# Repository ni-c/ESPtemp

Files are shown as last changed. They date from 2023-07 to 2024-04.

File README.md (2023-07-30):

# ESPtemp

Battery powered ESP8266 controlled temperature and humidity sensor communicating via MQTT protocol (with Home Assistant).

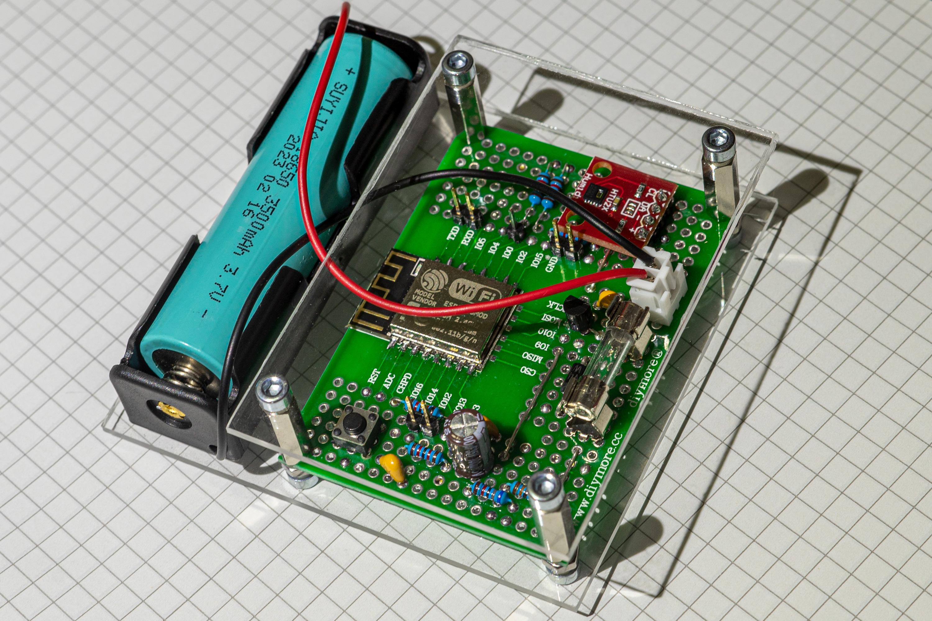
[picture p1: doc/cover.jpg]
ESPTemp v1.0 with case


ESPtemp is a battery-powered device that detects temperature and humidity and transmits them to a server (like [Home Assistant](https://www.home-assistant.io/)) via WiFi using [MQTT](https://mqtt.org/). It measures the current temperature, humidity and battery voltage, transmits them and then goes into deep sleep for 5 minutes to save energy. After that, the process is repeated. To make the connection to the WiFi as fast as possible, the WiFi channel and the MAC address of the router are stored in the RTC memory of the microcotroller and used to speed up the next connection attempt.

The device uses an ESP-12F microcontroller to process and transmit the data. Temperature and humidity are measured by a HTU21D sensor. The required operating voltage of 3.3V for the MCU and the sensor is provided by a MCP1700-3302E low dropout voltage regulator. The power supply is a lithium-ion battery type 18650 with 3.7V and 3500mAh. The protection of the circuit and the lithium-ion battery is ensured by a 200mA fine-wire fuse. The circuit is built on a double-sided prototype PCB board for ESP8266 and ESP32.

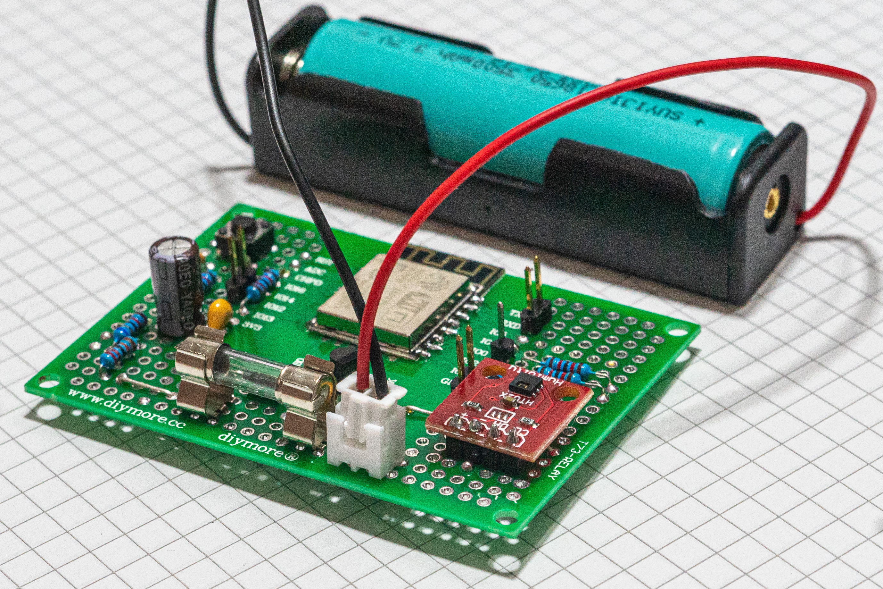
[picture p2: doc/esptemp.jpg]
ESPTemp v1.0 without case


### Part list

- [Prototype PCB board for ESP8266](https://aliexpress.com/item/32841008259.html)
- [ESP-12F](https://aliexpress.com/item/1005003766943788.html)
- [HTU21D](https://aliexpress.com/item/1005003761577887.html)
- [MCP1700](https://aliexpress.com/item/1005001608339185.html)
- [18650 lithium-ion battery](https://aliexpress.com/item/1005005313027198.html)
- [Battery Holder](https://aliexpress.com/item/1005005254487864.html)
- 1N4007 Diode
- 12 kΩ Resistor *(5 pieces)*
- 68 kΩ Resistor
- 220 kΩ Resistor
- 1000 µF Electrolyte capacitor
- 100 nF Ceramic capacitor *(2 pieces)*
- 1 nF Ceramic capacitor
- Micro push button switch (4 pin)
- Jumper connectors
- 200 mA Fuse
- Fuse holder
- Wire

## Schematics

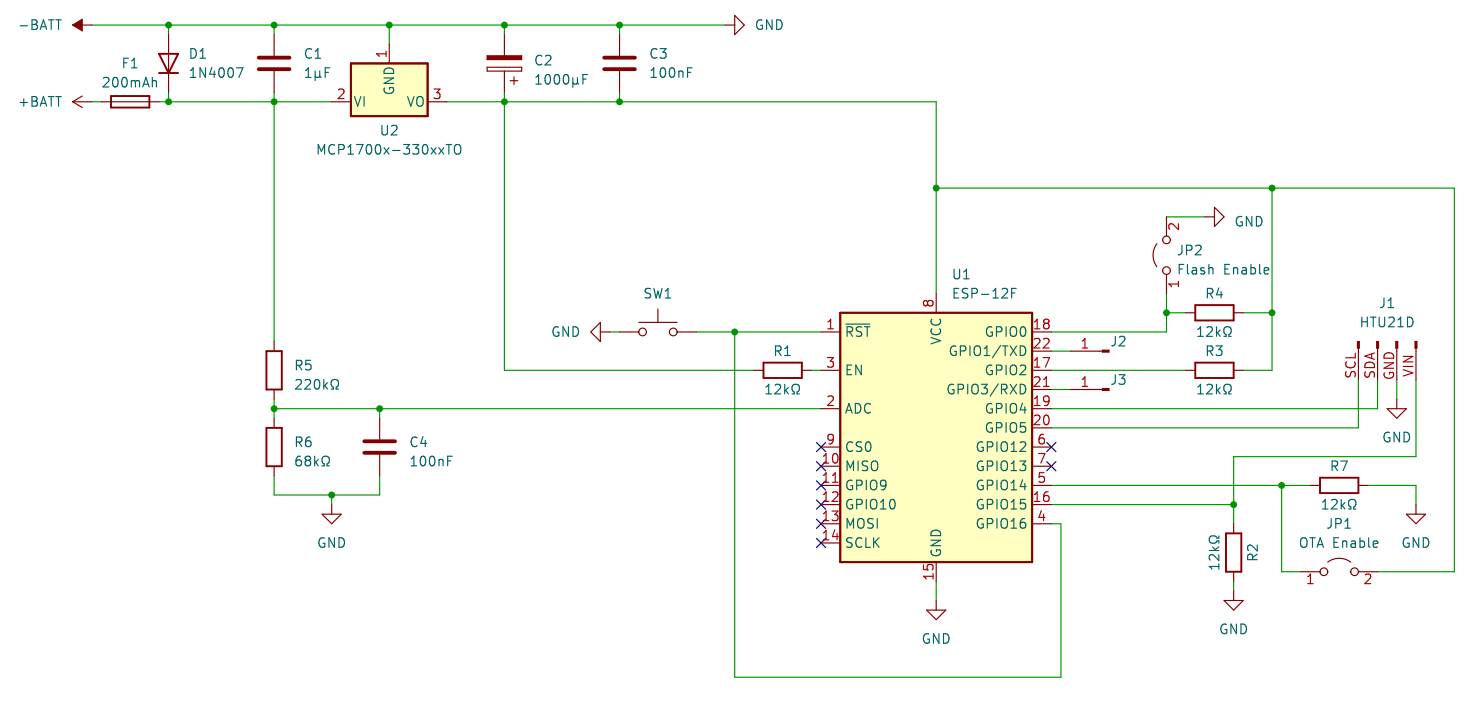
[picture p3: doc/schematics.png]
Schematics


## Perfboard layout

### Front

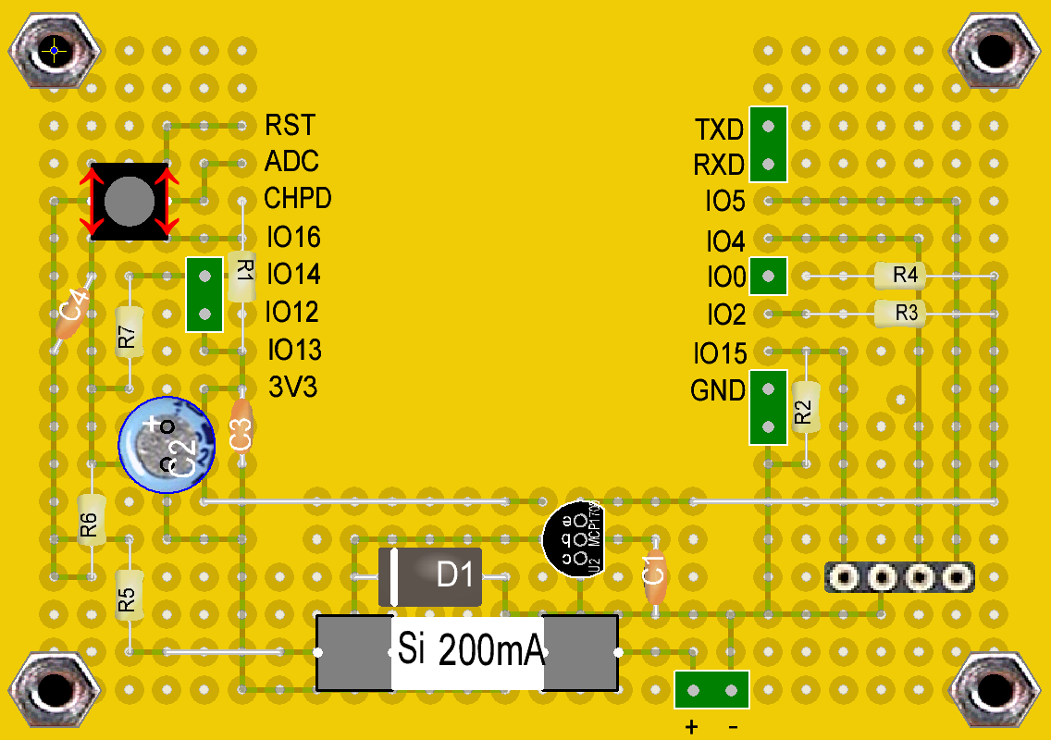
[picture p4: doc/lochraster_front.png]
Perfboard front


### Back

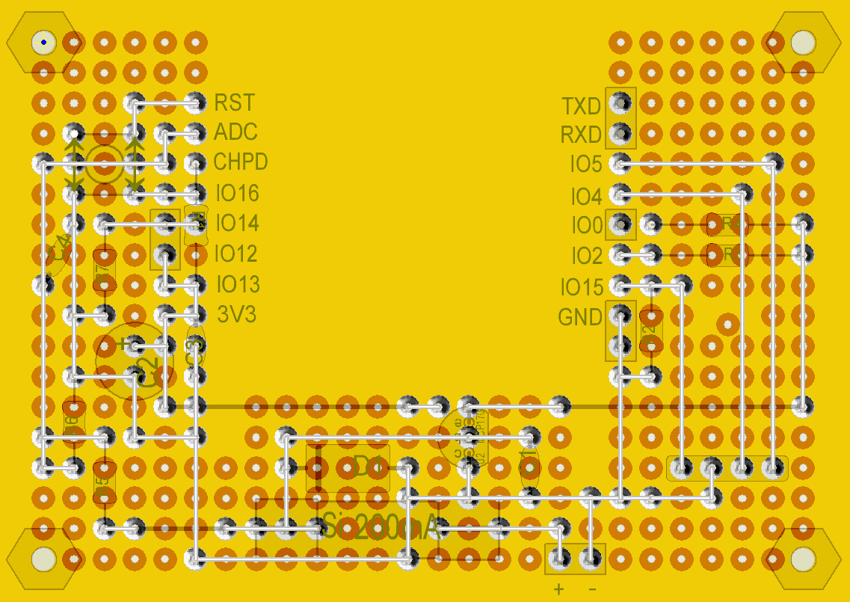
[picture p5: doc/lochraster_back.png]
Perfboard back


## Assembled

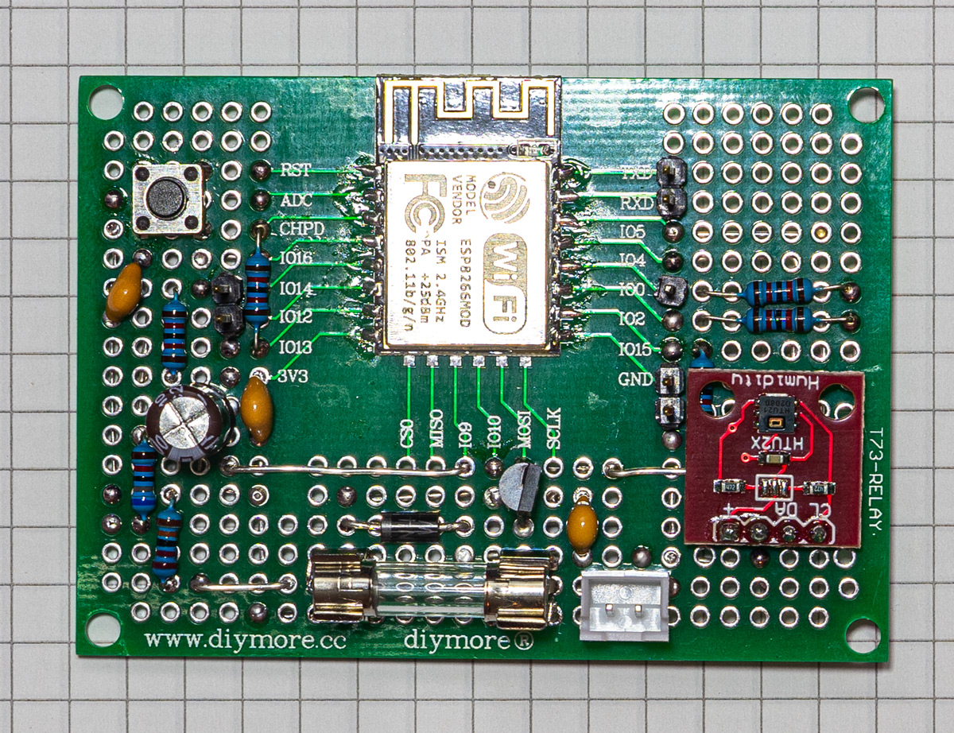
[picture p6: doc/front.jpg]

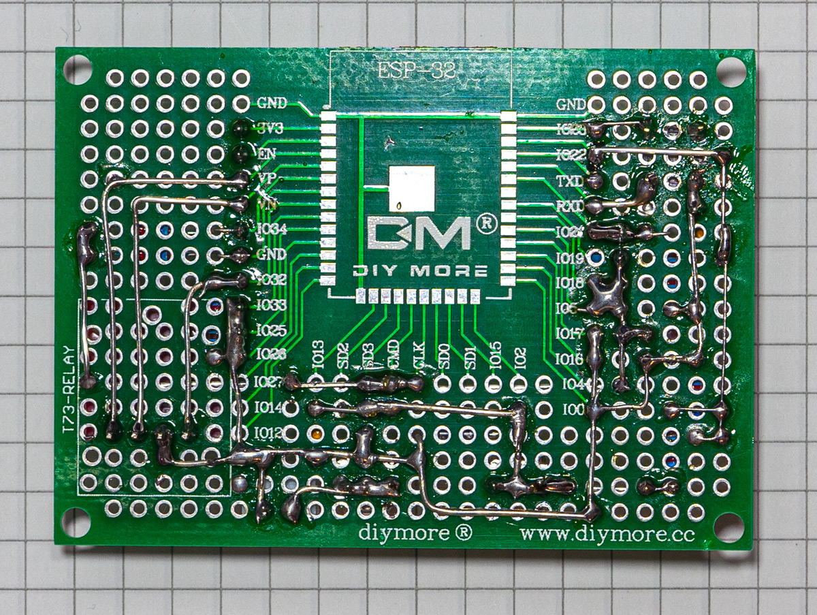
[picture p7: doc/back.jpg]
Perfboard back


## Firmware

The firmware is written in C++ using [Visual Studio Code](https://code.visualstudio.com/) with the [PlatformIO](https://platformio.org/) extension.

> ⚠️ Before building the firmware be sure to copy the file `include\config.h.example` to `include/config.h` and change the WiFi and MQTT credentials as well as the other settings in the new file.

### Flash via serial connection

Connect RX, TX and GND to your serial interface or [USB-to-TTL converter](https://aliexpress.com/item/32531899568.html). To [enter flash mode on the ESP-12F](https://lukelogbook.tech/2018/02/08/flash-code-to-esp8266-esp-12-module-step-by-step-guide/) you must connect **GPIO0** to **GND** and reset the MCU.

### Flash via OTA

To flash the ESP8266 Over-The-Air, connect **GPIO 14** to **VCC** and reset the ESP8266. After reboot it will enter the *"OTA wait loop"*. The flashing blue LED indicates that the MCU is waiting for the OTA firmware update.

## TODOs

- Create an [ESPHome](https://esphome.io/) configuration to use the hardware without the firmware provided here

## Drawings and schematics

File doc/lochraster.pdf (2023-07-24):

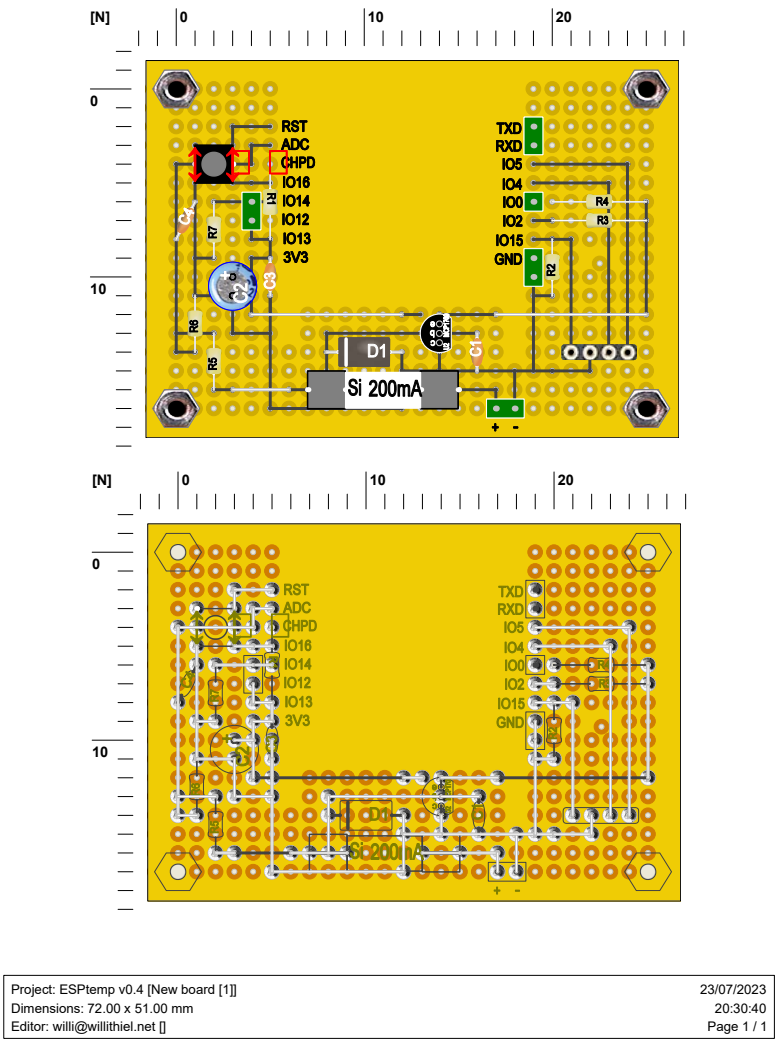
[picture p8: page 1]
23/07/2023 20:30:40 Page 1 / 1

Project: ESPtemp v0.4 [New board [1]]
Dimensions: 72.00 x 51.00 mm
Editor: willi@willithiel.net []

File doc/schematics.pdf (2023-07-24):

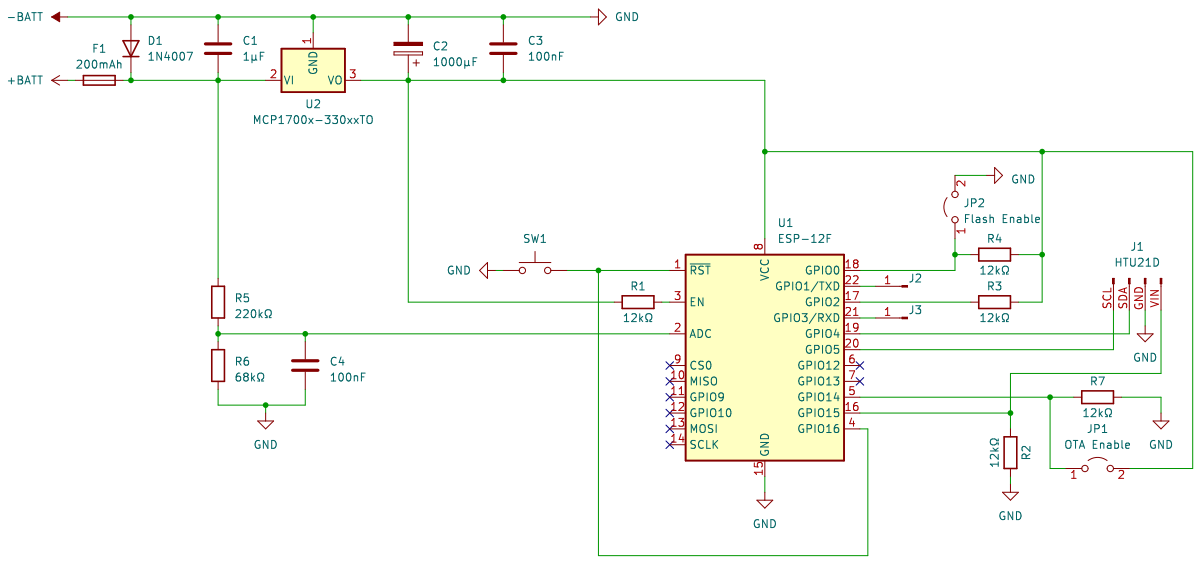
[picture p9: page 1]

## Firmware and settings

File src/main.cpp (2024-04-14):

#include <Arduino.h>
#include <Adafruit_HTU21DF.h>
#include <ESP8266WiFi.h>
#include <ArduinoOTA.h>
#include <PubSubClient.h>
#include <ArduinoJson.h>

#include "config.h"

#ifndef ESPTEMP_VERSION
#define ESPTEMP_VERSION "v1.1" /**< The current version of the ESPtemp firmware*/
#endif

#ifndef OTA_ENABLE_GPIO
#define OTA_ENABLE_GPIO 14 /**< Connect this GPIO Pin to VCC to enter OTA wait loop after reset */
#endif

#ifndef HTU21DF_VCC_GPIO
#define HTU21DF_VCC_GPIO 15 /**< VCC for HTU21DF sensor */
#endif

#ifndef SLEEPTIME
#define SLEEPTIME 300e6 /**< Time in deepsleep */
#endif

#ifndef SLEEPTIME_EXTENDED
#define SLEEPTIME_EXTENDED 21600e6 /**< Time in deepsleep if an error occured while trying to connect to wifi (to avoid battery drainage) */
#endif

#ifndef DEBUG
#define DEBUG 0 /**< Set to 1 to debug over serial */
#endif

#ifndef OTA
#define OTA 1 /**< Set to 1 to enable OTA waiting loop */
#endif

#if DEBUG
#define D_SerialBegin(...) Serial.begin(__VA_ARGS__)
#define D_print(...) Serial.print(__VA_ARGS__)
#define D_write(...) Serial.write(__VA_ARGS__)
#define D_println(...) Serial.println(__VA_ARGS__)
#define D_printf(...) Serial.printf(__VA_ARGS__)
#define D_timestamp() Serial.printf("[%lu] ", millis())
#else
#define D_SerialBegin(bauds)
#define D_print(...)
#define D_write(...)
#define D_println(...)
#define D_printf(...)
#define D_timestamp()
#endif

unsigned long startMillis;

float humidity;
float temperature;
float batteryVoltage;
int8_t batteryPercentage;
uint_fast16_t adcValue;
char error[15];

uint8_t wifiRetries = 0;
uint_fast16_t i = 0;

bool isHTU21DFready = false;
bool isBatteryVoltageReady = false;
bool isWifiStarted = false;
bool isWifiReady = false;
bool isRegularWifi = false;
bool isMQTTStarted = false;
bool isMQTTReady = false;
bool isRtcValid = false;
bool isOTAEnabled = false;

uint8_t ledState = HIGH;

Adafruit_HTU21DF htu = Adafruit_HTU21DF();

WiFiClient wifiClient;
PubSubClient pubSubclient(wifiClient);

struct
{
    uint32_t crc32;    // 4 bytes
    uint8_t channel;   // 1 byte,   5 in total
    uint8_t ap_mac[6]; // 6 bytes, 11 in total
} rtcData;

// the CRC routine
uint32_t calculateCRC32(const uint8_t *data, size_t length)
{
    uint32_t crc = 0xffffffff;
    while (length--)
    {
        uint8_t c = *data++;
        for (uint32_t i = 0x80; i > 0; i >>= 1)
        {
            bool bit = crc & 0x80000000;
            if (c & i)
            {
                bit = !bit;
            }

            crc <<= 1;
            if (bit)
            {
                crc ^= 0x04c11db7;
            }
        }
    }

    return crc;
}

// Read the battery voltage from the ADC
float readBatteryVoltage(void)
{
    adcValue = analogRead(A0);
    batteryVoltage = adcValue * 0.004;
    batteryPercentage = (int8_t)((adcValue - 863) / 1.6);

    if (batteryVoltage <= 3.3)
    {
        D_timestamp();
        D_println("Battery low. Going to long deep sleep. Good night.");
        ESP.deepSleep(0);
    }

    D_timestamp();
    D_println("ADC Reading ready");
    D_timestamp();
    D_printf("Battery voltage: %.1f V, Battery Percentage: %i", batteryVoltage, batteryPercentage);
    D_println();
    return batteryVoltage;
}

void setup()
{
    D_SerialBegin(115200);

    // internal LED off
    pinMode(LED_BUILTIN, OUTPUT);
    digitalWrite(LED_BUILTIN, HIGH);

    // we disable WiFi, coming from DeepSleep, as we do not need it right away
    WiFi.mode(WIFI_OFF);
    WiFi.forceSleepBegin();

    D_println();
    D_timestamp();
    D_printf("CpuFreqMHz: %u MHz\n", ESP.getCpuFreqMHz());
    D_timestamp();
    D_print("MAC Address: ");
    D_println(WiFi.macAddress());

    // enable HTU21DF_VCC
    pinMode(HTU21DF_VCC_GPIO, OUTPUT);
    digitalWrite(HTU21DF_VCC_GPIO, HIGH);
    htu.begin();

    // Wait minimum sampling period
    startMillis = millis();

    if (ESP.rtcUserMemoryRead(0, (uint32_t *)&rtcData, sizeof(rtcData)))
    {
        // Calculate the CRC of what we just read from RTC memory, but skip the first 4 bytes as that's the checksum itself.
        uint32_t crc = calculateCRC32(((uint8_t *)&rtcData) + 4, sizeof(rtcData) - 4);
        if (crc == rtcData.crc32)
        {
            isRtcValid = true;
        }
    }

#if OTA
#if DEBUG
    ArduinoOTA.onStart([]()
                       {
        String __type;
        if (ArduinoOTA.getCommand() == U_FLASH)
            __type = "sketch";
        else // U_SPIFFS
            __type = "filesystem";
        D_timestamp();
        D_println("(OTA) Update starting: " + __type); });

    ArduinoOTA.onEnd([]()
                     {
        D_timestamp();
        D_println("(OTA) Update finished "); });

    ArduinoOTA.onError([](ota_error_t error)
                       {
        D_print("(OTA) Error[");
        D_print(error);
        D_print("]: ");
        if (error == OTA_AUTH_ERROR)
            D_println("Auth Failed");
        else if (error == OTA_BEGIN_ERROR)
            D_println("Begin Failed");
        else if (error == OTA_CONNECT_ERROR)
            D_println("Connect Failed");
        else if (error == OTA_RECEIVE_ERROR)
            D_println("Receive Failed");
        else if (error == OTA_END_ERROR)
            D_println("End Failed"); });
#endif
    pinMode(OTA_ENABLE_GPIO, INPUT);
    isOTAEnabled = (digitalRead(OTA_ENABLE_GPIO) == HIGH);
    if (isOTAEnabled)
    {
        D_timestamp();
        D_println("GPIO 14 is high, OTA enabled");
    }
    else
    {
        D_timestamp();
        D_println("GPIO 14 is low, OTA not enabled");
    }
#endif
    D_timestamp();
    D_println("Setup finished");
}

void loop()
{

    /*
     * Step 1:
     * Read temperature and humidity from HTU21DF
     */
    if (!isHTU21DFready)
    {
        // Read sensors
        humidity = htu.readHumidity();
        temperature = htu.readTemperature();

        D_timestamp();
        D_println("HTU21DF Reading ready");
        D_timestamp();
        D_printf("Temperature: %.1f, Humidity: %.1f", temperature, humidity);
        D_println();

        isHTU21DFready = true;
        digitalWrite(HTU21DF_VCC_GPIO, LOW);
    }

    /*
     * Step 2:
     * Start WiFi connection
     */
    if (!isWifiStarted)
    {
        D_timestamp();
        D_println("Starting WiFi");

        WiFi.forceSleepBegin();
        delay(1);
        WiFi.forceSleepWake();
        delay(1);

        // Disable the WiFi persistence.  The ESP8266 will not load and save WiFi settings unnecessarily in the flash memory.
        WiFi.persistent(false);

        // Bring up the WiFi connection
        WiFi.mode(WIFI_STA);
        WiFi.config(ip, dns, gateway, subnet);
        WiFi.hostname(MQTT_CLIENT);

        if (isRtcValid)
        {
            // The RTC data was good, make a quick connection
            D_timestamp();
            D_println("RTC OK, initiate quick connection");
            WiFi.begin(WLAN_SSID, WLAN_PASSWD, rtcData.channel, rtcData.ap_mac, true);
            isRegularWifi = false;
        }
        else
        {
            // The RTC data was not valid, so make a regular connection
            D_timestamp();
            D_println("RTC BAD, initiate regular connection");
            WiFi.begin(WLAN_SSID, WLAN_PASSWD);
            isRegularWifi = true;
        }

        isWifiStarted = true;
    }

    /*
     * Step 3:
     * Read battery voltage from ADC
     */
    if (!isBatteryVoltageReady)
    {
        isBatteryVoltageReady = true;
        readBatteryVoltage();
    }

    /*
     * Step 4:
     * If WiFi is ready: Initialize MQTT client
     * OR
     * Start OTA waiting loop if OTA_ENABLE_GPIO is pulled HIGH
     */
    if (!isWifiReady)
    {
        if (WiFi.status() == WL_CONNECTED)
        {
            D_timestamp();
            D_print("WiFi connected (");
            D_print(WiFi.localIP());
            D_println(")");
            pubSubclient.setServer(MQTT_BROKER, MQTT_PORT);
            isWifiReady = true;

            if (isOTAEnabled)
            {
                D_timestamp();
                D_println("Starting OTA");
                ArduinoOTA.setHostname(MQTT_CLIENT);
                ArduinoOTA.begin();
            }
        }
        else if (((millis() - startMillis) > 5000) && (!isRegularWifi))
        {
            // Try regular connection
            D_timestamp();
            D_println("WiFi timeout, retrying regular connection");
            WiFi.disconnect();
            delay(5);
            WiFi.forceSleepBegin();
            delay(1);
            WiFi.forceSleepWake();
            delay(1);
            WiFi.begin(WLAN_SSID, WLAN_PASSWD);
            isRtcValid = false;
            isRegularWifi = true;
        }
        else if ((millis() - startMillis) > 20000)
        {
            // Wifi connection failed, go to extended sleep
            WiFi.disconnect(true);
            D_timestamp();
            D_println("Connection to WiFi failed, going to extended sleep");
            ESP.deepSleep(SLEEPTIME_EXTENDED, WAKE_RF_DISABLED);
        }
    }
    /*
     * Step 5:
     * Connect to MQTT broker
     */
    else if (!isMQTTStarted)
    {
        if (!pubSubclient.connected())
        {
            D_timestamp();
            D_println("Connecting to MQTT broker");
            pubSubclient.connect(MQTT_CLIENT, MQTT_USER, MQTT_PASSWORD);
            delay(10);
        }
        else
        {
            D_timestamp();
            D_println("MQTT connected");
            isMQTTStarted = true;
        }
    }

    /*
     * Step 5:
     * If all readings are made and WiFi is ready, transmit MQTT data
     */
    if (isMQTTStarted && isWifiReady && isHTU21DFready && !isMQTTReady)
    {
        DynamicJsonDocument doc(1024);
        doc["temperature"] = (int)roundf(10 * temperature) / 10.0;
        doc["humidity"] = (int)roundf(10 * humidity) / 10.0;
        doc["batteryVoltage"] = (int)roundf(100 * batteryVoltage) / 100.0;
        doc["batteryPercentage"] = batteryPercentage;
        doc["firmwareVersion"] = ESPTEMP_VERSION;

        char json[128];
        serializeJson(doc, json);

        D_timestamp();
        D_print("MQTT Publish: ");
        D_print(MQTT_TOPIC);
        D_print(" ");
        D_println(json);

        pubSubclient.loop();
        pubSubclient.publish(MQTT_TOPIC, json);
        delay(10);

        isMQTTReady = true;
    }

    if (!isOTAEnabled)
    {
        /*
         * Step 6:
         * Save WiFi data to RTC and go to deep sleep again
         */
        if (isMQTTReady)
        {
            // Write current connection info to RTC
            if (!isRtcValid)
            {
                rtcData.channel = WiFi.channel();
                memcpy(rtcData.ap_mac, WiFi.BSSID(), 6); // Copy 6 bytes of BSSID (AP's MAC address)
                rtcData.crc32 = calculateCRC32(((uint8_t *)&rtcData) + 4, sizeof(rtcData) - 4);
                ESP.rtcUserMemoryWrite(0, (uint32_t *)&rtcData, sizeof(rtcData));
            }

            WiFi.disconnect(true);

            D_timestamp();
            D_println("DONE, going to sleep");
            ESP.deepSleep(SLEEPTIME, WAKE_RF_DISABLED);
        }
        else if ((millis() - startMillis) > 25000)
        {
            WiFi.disconnect(true);
            D_timestamp();
            D_println("TIMEOUT, going to sleep");
            ESP.deepSleep(SLEEPTIME, WAKE_RF_DISABLED);
        }
    }
    /*
     * OTA wait loop
     */
    else
    {
#if OTA
        // Blink LED
        if ((millis() % 1000) > 500)
        {
            ledState = HIGH;
        }
        else
        {
            ledState = LOW;
        }

        // Protect battery 
        i++;
        if (i == 1024) {
            i = 0;
            readBatteryVoltage();
        }

        digitalWrite(LED_BUILTIN, ledState);
        ArduinoOTA.handle();
#endif
    }
}

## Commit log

2023-07-30 Update README.md
    Added new image with acrylic glass case
2023-11-23 Fixed battery drain when WiFi is not available
    [main.cpp]
2024-04-05 DEBUG flag bugfix and baud rate setting
    [main.cpp]
2024-04-14 Added battery protection to OTA mode
2026-10-20 Back off from failed connections and test the firmware natively
    When WiFi was down, v1.1 slept a fixed 6 hours after one failed
    attempt. That is longer than the ESP8266 can sleep at once
    (ESP.deepSleepMax(), about 3.5 hours), a single router reboot cost 6
    hours of data, and a broker that does not answer was not covered at all:
    the device stayed awake 25 seconds every 5 minutes.
    Failed attempts are now counted in RTC memory, and the wait doubles
    from 10 minutes to at most 2 hours (BACKOFF_MAX_SLEEPTIME). It is made
    of single 5-minute deep sleeps; a wake that only counts down keeps the
    radio and the sensor off. A broker timeout counts like a WiFi failure,
    a connection the access point refuses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
